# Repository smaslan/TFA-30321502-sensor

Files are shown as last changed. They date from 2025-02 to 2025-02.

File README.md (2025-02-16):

# TFA Dostmann 30.3215.02 compatible sensor

Recently, one of my meteo sensors TFA Dostmann 30.3215.02 died (rusted battery contacts). 
Not so long ago I decoded its data packets and made logging receiver for this particular type ([TFA-30321502-decoder](https://github.com/smaslan/TFA-30321502-decoder)). 
So, I decided to make a clone of this sensor based on the decoded format and it seems to work fine.

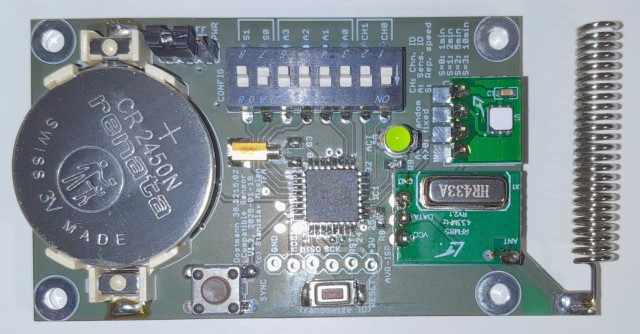
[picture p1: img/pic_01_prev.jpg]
Prototype


## Hardware

As usually, I used 8-bit AVR [ATmega48PB](https://www.microchip.com/en-us/product/atmega48pb).
Temperature and humidity sensor is [Hoperf TH06](https://www.hoperf.com/sensor/temperature_sensor/TH06.html).
Transmitter is cheap 433.92MHz module [Hoperf RFM85W-433](https://datasheet4u.com/datasheet-pdf/HOPERF/RFM85W-433D/pdf.php?id=748076) with AM modulation but it would work with any other module.
Both sensor and transmitter have switchable power to reduce idle consumption to near zero. Battery voltage sensing is also from the switched bus.
Intended power supply is from a single 3V cell Renata 2450n with approx. 500mAh capacity but it can of course run from 2xAAA cells or so.
Idle current is few uA and average charge consumed per single transmission is approx. 1uAh, so with 1 minute reporting period it should last about a year on the battery.
Configuration of the module is done by 8 DIP switches (see below).
Diagram and PCB in Eagle 6.5.0 are available at [TFA_sensor/](./TFA_sensor/) 

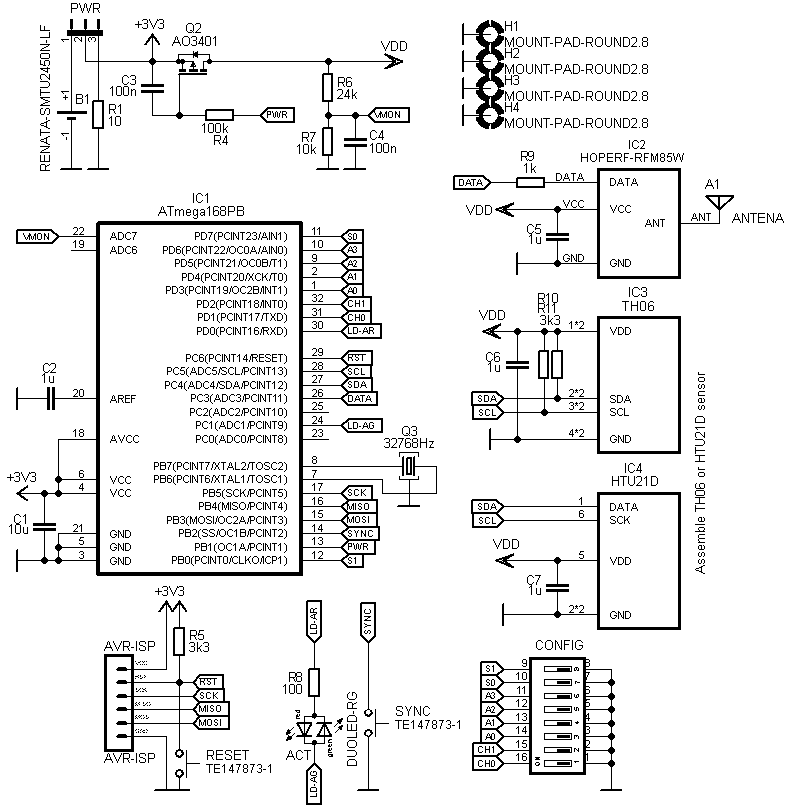
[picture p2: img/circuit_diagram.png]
Circuit diagram


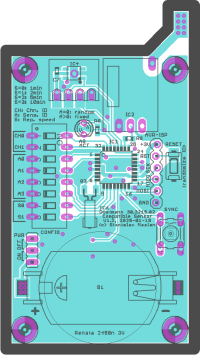
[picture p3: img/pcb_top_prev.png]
PCB top
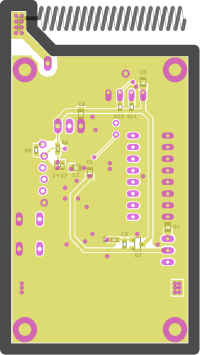
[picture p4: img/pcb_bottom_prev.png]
PCB bottom
 

## AVR Firmware

Firmware for AVR is written in [Microchip Studio](https://www.microchip.com/en-us/tools-resources/develop/microchip-studio) using AVRGCC compiler. 
AVR main clock is internal RC at 1MHz which is more than enough. Timer 2 is configured to use external 32768Hz crystal to periodically wakeup AVR from power save mode for the auto reporting.
Reporting period can be set by DIP switches and it is randomized +-5% to prevent permanent overlap with other sensors. Reporting can be also forced by SYNC button same as with original sensors.
Pressing RESET or cycling power will regenerate random device ID code same as with original sensor. 
When SYNC button or periodic wakeup occures, it will enable power bus, read sensor data and start transmission in format described in 
[TFA-30321502-decoder](https://github.com/smaslan/TFA-30321502-decoder). Then goes sleep again. The whole cycle takes less than 1 second (transmission is slow).
Dual color LED will blink green if battery voltage is ok and red if not.

DIP switches configuration:
```
CH[1..0]: Channel code, values 0, 1 and 2 (equal to original sensor switch positions 1, 2, 3), 
          this FW allows codes up to 3 but it won't be recognized by original meteo base station!
A[3..0]:  Sensor ID code: 0 will generate random ID after power up or RESET,
                          1 to 15 will force A value as sensor ID.
S[1..0]:  Reporting period (0: 1min, 1: 2min, 2: 5min, 3: 10min).                             
```

AVR fuse bits are set to default:
```
 Extended byte: BOOTRST = 1, BOOTSZ[1..0] = 00 
 High byte: BODLEVEL = 111, EESAVE = 1, WDTON = 1, SPIEN = 0, DWEN = 1, RSTDISBL = 1
 Low byte: CKSEL[3..0] = 0010, SUT[1..0] = 10, CKOUT = 1, CKDIV8 = 0
```
Firmware is available at [TFA_sensor/fw_tfa_sensor/](./TFA_sensor/fw_tfa_sensor).

## License
All parts of the project are distributed under [MIT license](./LICENSE.txt).

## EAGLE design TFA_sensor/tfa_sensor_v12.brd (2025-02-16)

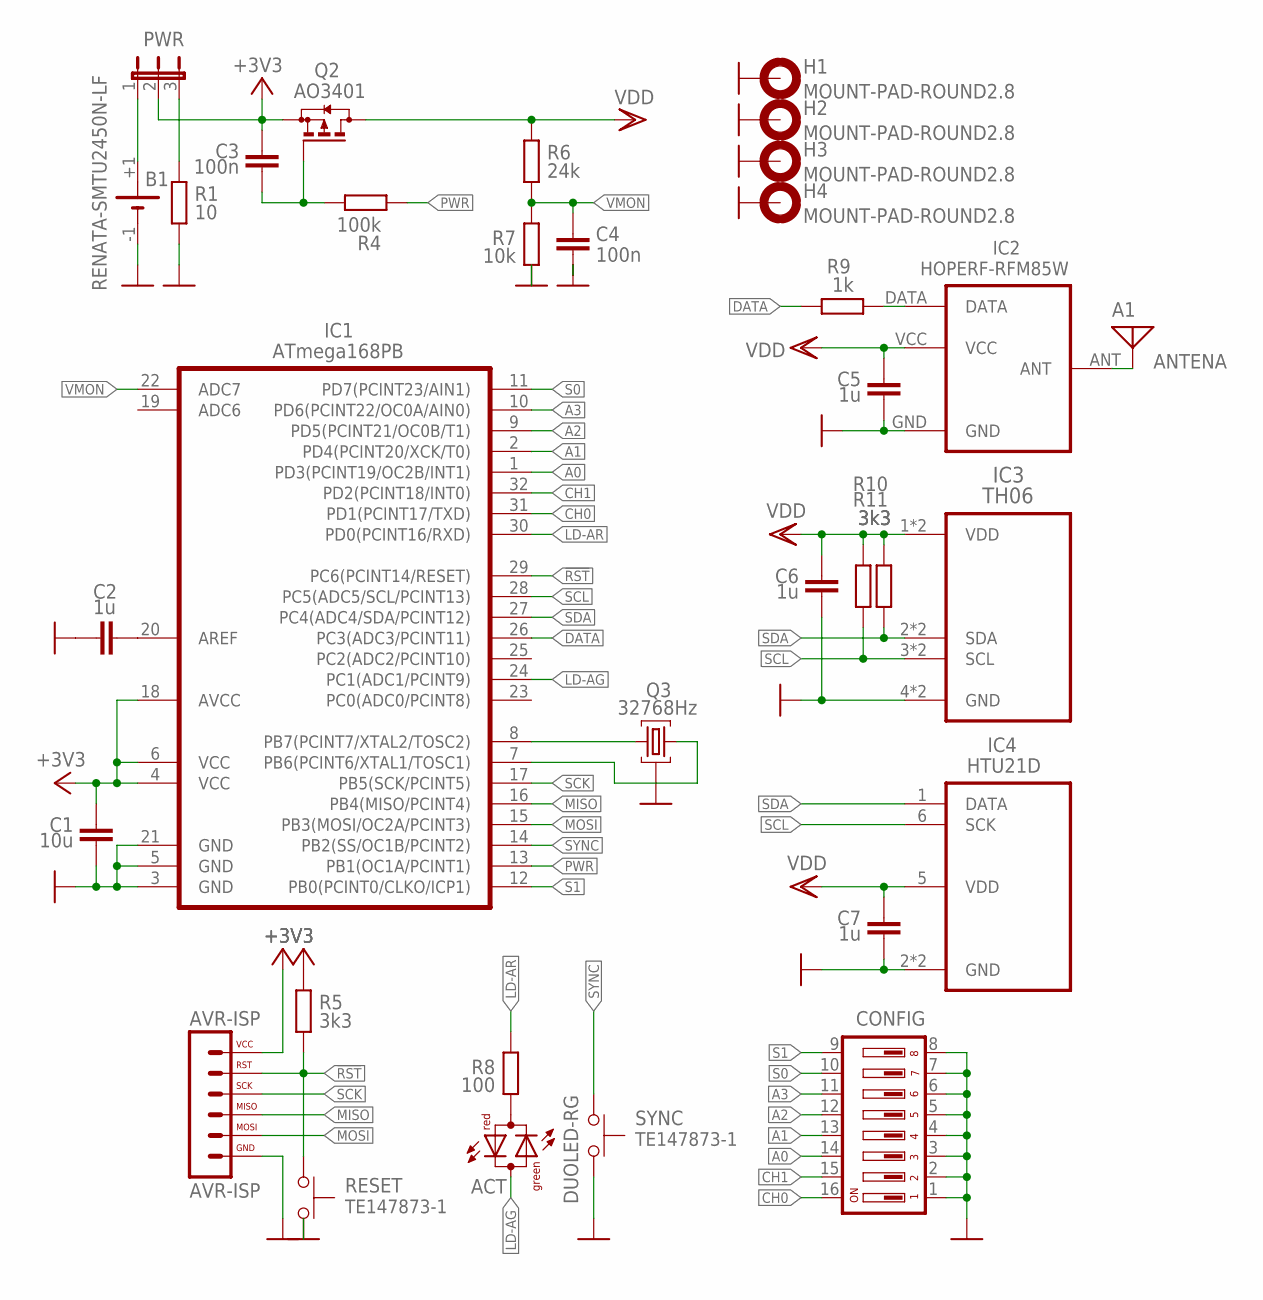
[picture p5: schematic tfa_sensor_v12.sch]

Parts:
A1: ANTENA; ANT-433MHZ-SPIRAL
ACT: DUOLED-RG; LED3MM
AVR-ISP: AVR-ISP; SIL6-RNDPRESS
B1: RENATA-SMTU2450N-LF
C1: 10u; C0805K
C2, C5, C6: 1u; C0805K
C3, C4: 100n; C0603K
C7: 1u; C0603K
CONFIG: DIP08YL
H1, H2, H3, H4: MOUNT-PAD-ROUND2.8; 2,8-PAD
IC1: ATmega168PB; TQFP32
IC2: HOPERF-RFM85W
IC3: TH06
IC4: HTU21D; DFN6-RH
PWR: JP2EB; JP2YB
Q2: AO3401; SOT23
Q3: 32768Hz; CMJ206T
R1: 10; R0805
R4: 100k; R0603
R5, R10, R11: 3k3; R0603
R6: 24k; R0603
R7: 10k; R0603
R8: 100; R0603
R9: 1k; R0603
RESET: TE147873-1; TE-147873-1
SYNC: TE147873-1; CUDL1

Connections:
!RST: AVR-ISP.5, IC1.29 (PC6(PCINT14/RESET)), R5.1, RESET.P$2
+3V3: AVR-ISP.6, C1.1, C3.1, IC1.4 (VCC), IC1.6 (VCC), IC1.18 (AVCC), PWR.2, Q2.2 (S), R5.2
A0: CONFIG.14, IC1.1 (PD3(PCINT19/OC2B/INT1))
A1: CONFIG.13, IC1.2 (PD4(PCINT20/XCK/T0))
A2: CONFIG.12, IC1.9 (PD5(PCINT21/OC0B/T1))
A3: CONFIG.11, IC1.10 (PD6(PCINT22/OC0A/AIN0))
ANT: A1.P$1, IC2.ANT
CH0: CONFIG.16, IC1.31 (PD1(PCINT17/TXD))
CH1: CONFIG.15, IC1.32 (PD2(PCINT18/INT0))
DATA: IC1.26 (PC3(ADC3/PCINT11)), R9.2
GND: AVR-ISP.1, B1.-1 (-), C1.2, C2.1, C4.2, C5.2, C6.2, C7.2, CONFIG.1, CONFIG.2, CONFIG.3, CONFIG.4, CONFIG.5, CONFIG.6, CONFIG.7, CONFIG.8, H1.B2,8, H2.B2,8, H3.B2,8, H4.B2,8, IC1.3 (GND), IC1.5 (GND), IC1.21 (GND), IC2.GND, IC3.4 (GND), IC3.14 (GND), IC4.2 (GND), IC4.EP (GND), Q3.S (3), R1.2, R7.1, RESET.P$1, SYNC.1, SYNC.2
LD-AG: ACT.K (C), IC1.24 (PC1(ADC1/PCINT9))
LD-AR: IC1.30 (PD0(PCINT16/RXD)), R8.2
MISO: AVR-ISP.3, IC1.16 (PB4(MISO/PCINT4))
MOSI: AVR-ISP.2, IC1.15 (PB3(MOSI/OC2A/PCINT3))
unnamed: B1.+1 (+), PWR.1
unnamed: PWR.3, R1.1
unnamed: ACT.A, R8.1
unnamed: IC1.8 (PB7(PCINT7/XTAL2/TOSC2)), Q3.X2 (2)
unnamed: IC1.7 (PB6(PCINT6/XTAL1/TOSC1)), Q3.X1 (1)
unnamed: C2.2, IC1.20 (AREF)
unnamed: IC2.DATA, R9.1
unnamed: C3.2, Q2.1 (G), R4.2
PWR: IC1.13 (PB1(OC1A/PCINT1)), R4.1
S0: CONFIG.10, IC1.11 (PD7(PCINT23/AIN1))
S1: CONFIG.9, IC1.12 (PB0(PCINT0/CLKO/ICP1))
SCK: AVR-ISP.4, IC1.17 (PB5(SCK/PCINT5))
SCL: IC1.28 (PC5(ADC5/SCL/PCINT13)), IC3.3 (SCL), IC3.13 (SCL), IC4.6 (SCK), R10.2
SDA: IC1.27 (PC4(ADC4/SDA/PCINT12)), IC3.2 (SDA), IC3.12 (SDA), IC4.1 (DATA), R11.2
SYNC: IC1.14 (PB2(SS/OC1B/PCINT2)), SYNC.3, SYNC.4
VDD: C5.1, C6.1, C7.1, IC2.VCC, IC3.1 (VDD), IC3.11 (VDD), IC4.5 (VDD), Q2.3 (D), R6.2, R10.1, R11.1
VMON: C4.1, IC1.22 (ADC7), R6.1, R7.2

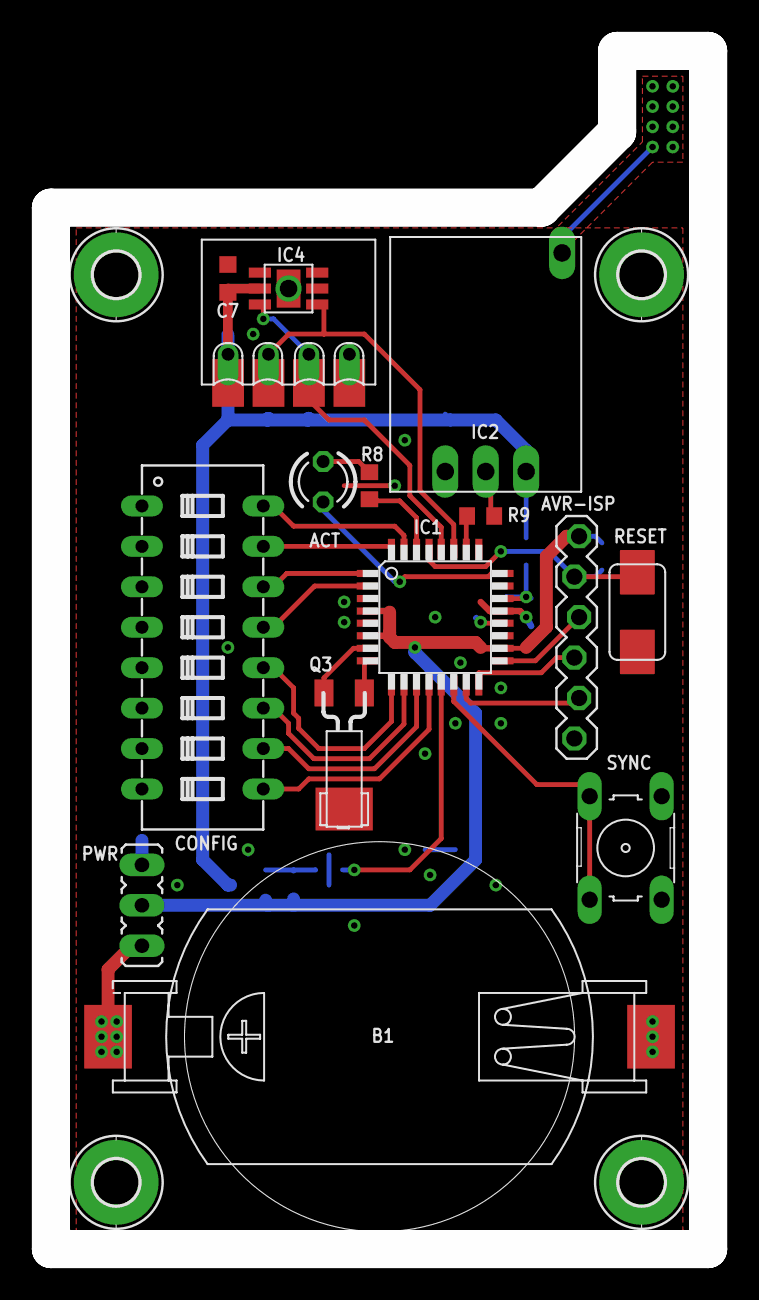
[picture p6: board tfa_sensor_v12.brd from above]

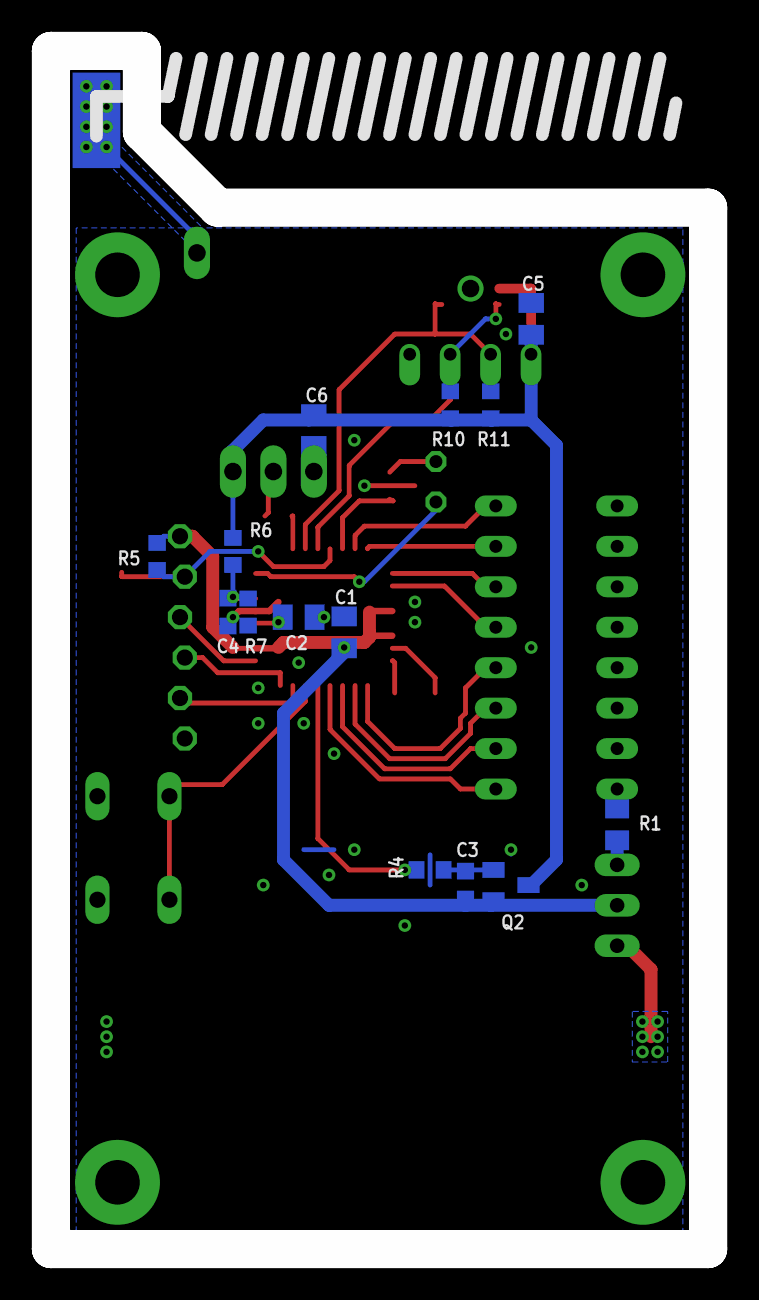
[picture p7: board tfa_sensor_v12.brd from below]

Board: 2 copper layers, 41.3 x 75.2 mm, 34 parts (15 on the bottom side), 32 nets.

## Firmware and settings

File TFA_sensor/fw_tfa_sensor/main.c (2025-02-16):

/*
 * TFA Dostmann 30.3215.02 compatible sensor transmitter.
 * This code uses TH06 ambient sensor to periodically read temperature and RH
 * and sends packet compatible with TFA Dostmann 30.3215.02 sensors via any 433.92MHz radio module.
 *
 * Sensor channel code 1 to 4 is defined by DIP switches.
 * Sensor identifier is set either manually by DIPs in range 1 to 15 or random after each reset as for original sensor when DIPs set to 0.
 * Reporting period can be set to 1, 2, 5 or 10 minutes by another DIPs. Actual period is randomized +/-5%.
 *
 * Designed for ATmega48PB, which is about minimum to fit.
 * Wakeup timer uses 32768Hz crystal on Timer 2.
 * Main clock is internal 1MHz RC clock (default fuses).
 * It is designed for a 3V lithium battery Renata 2450n with ~500mAh capacity.
 * It should last for about a year with 1 minute reporting period (consumes ~1uAh per transmission).
 * Idle power is few uA. Actual lifetime depends on transmitter power.
 *
 * More details on HW on project GitHub url:
 * https://github.com/smaslan/TFA-30321502-sensor
 *
 * (c) 2025, Stanislav Maslan, s.maslan@seznam.cz
 * V1.2, 2025-02-15
 *
 * The code and all its part are distributed under MIT license
 * https://opensource.org/licenses/MIT.
 */ 

#include <avr/io.h>
#include <avr/sleep.h>
#include <avr/pgmspace.h>
#include <avr/interrupt.h>
#include <avr/wdt.h>
#include <avr/sfr_defs.h>
#include <util/twi.h>
#include <util/atomic.h>
#include <util/delay_basic.h>
#include <util/delay.h>
#include <stdlib.h>

#include "main.h"

// --- jump to address ---
#define boot_start(boot_addr) {goto *(const void*)boot_addr;}



//----------------------------------------------------------------------------------
// analog ADC stuff
//----------------------------------------------------------------------------------

// ADC data and stuff
typedef struct{
	volatile uint16_t a_vmon;
	volatile uint8_t rand;
}TADC;
TADC adc_data;

#define ADC_VREF 1.1f
#define ADC_VMON_DIV (10000.0/(10000.0 + 24000.0))
#define ADC_GAIN (ADC_VREF/(ADC_AVG*1024.0f))
#define ADC_VMON_CAL (ADC_GAIN/ADC_VMON_DIV)

// ADC conversion done ISR
ISR(ADC_vect)
{
	// average buffer
	static uint8_t avg_cnt = ADC_AVG;

	// get new value
	uint16_t adc = ADC;
		
	static uint16_t vmon = 0;
	vmon += adc;
	avg_cnt--;
	if(!avg_cnt)
	{
		avg_cnt = ADC_AVG;
		adc_data.a_vmon = vmon; vmon = 0;

		// generate random-like number
		uint8_t rng = (adc&0xFF)^(adc>>8);
		rng = (rng>>4)^(rng&0x0F);
		rng = (rng>>2)^(rng&0x03);
		rng = (rng>>1)^(rng&0x01);
		adc_data.rand = (adc_data.rand<<1) | rng;
	}
	
	// start next conversion
	sbi(ADCSRA,ADIF);
	sbi(ADCSRA,ADSC);
}

// get VMON voltage [V]
float adc_get_vmon()
{
	uint16_t a_vmon = 0;
	ATOMIC_BLOCK(ATOMIC_RESTORESTATE)
	{
		a_vmon = adc_data.a_vmon;
	}
	return(ADC_VMON_CAL*a_vmon);
}


// init ADC
void adc_init()
{
	// initial ADC setup (AVcc ref)
	ADMUX = (3<<REFS0)|(0<<ADLAR)|(VMON_ADC_MUX<<MUX0);
	ADCSRA = (1<<ADEN)|(0<<ADATE)|(1<<ADIE)|(2<<ADPS0);
	ADCSRB = (0<<ADTS0);
	
	// start ADC conversion loop
	sbi(ADCSRA,ADSC);
	
	// initial measured value
	adc_data.a_vmon = 0;
}

// idle ADC before sleep
void adc_idle()
{
	ADCSRA = 0;
}


//----------------------------------------------------------------------------------
// DIP switches stuff
//----------------------------------------------------------------------------------
// init DIP switches
void dip_init()
{
	// channel
	CH_ddr &= ~(CH_msk<<CH0);
	CH_port |= (CH_msk<<CH0);

	// address id
	A_ddr &= ~(A_msk<<A0);
	A_port |= (A_port<<A0);

	// speed code
	cbi(S0_ddr, S0);
	sbi(S0_port, S0);
	cbi(S1_ddr, S1);
	sbi(S1_port, S1);
}

// set DIP to power down mode
void dip_idle()
{
	CH_port &= ~(CH_msk<<CH0);
	A_port &= ~(A_msk<<A0);
	cbi(S0_port, S0);
	cbi(S1_port, S1);
}

// get address id
uint8_t dip_get_addr()
{
	return(15 - ((A_pin >> A0) & A_msk));
}

// get channel id
uint8_t dip_get_chn()
{
	return(3 - ((CH_pin >> CH0) & CH_msk));
}

// get speed code
uint8_t dip_get_speed()
{
	uint8_t speed = 0;
	bcopy(speed, 0, S0_pin, S0);
	bcopy(speed, 1, S1_pin, S1);
	return(3 - speed);
}





//----------------------------------------------------------------------------------
// I2C STUFF
//----------------------------------------------------------------------------------

#define i2c_start() TWCR = (1<<TWINT) | (1<<TWEN) | (1<<TWSTA)
#define i2c_stop() TWCR = (1<<TWINT) | (1<<TWEN) | (1<<TWSTO)
#define i2c_data_out(data)	TWDR = (data); TWCR = (1<<TWINT) | (1<<TWEN)
#define i2c_read(ack) TWCR = (1<<TWINT) | (1<<TWEN) | ((ack)<<TWEA)

// set timeout value [ms]
volatile uint16_t i2c_timeout;
void i2c_timeout_set(uint16_t timeout)
{
	ATOMIC_BLOCK(ATOMIC_FORCEON)
	{
		i2c_timeout = timeout;
	}
}

// timeout done?
uint8_t i2c_timeout_done()
{
	uint16_t timeout;
	ATOMIC_BLOCK(ATOMIC_FORCEON)
	{
		timeout = i2c_timeout;
	}
	return(timeout == 0);
}

// timeout timer ISR
ISR(TIMER0_COMPA_vect, ISR_NOBLOCK)
{
	uint16_t time = i2c_timeout;
	if(time)
		time--;
	i2c_timeout = time;
}

// initialize I2C
void i2c_init()
{
	// I2C as master
	TWCR = (1<<TWEN)|(1<<TWEA);
	TWBR = (uint8_t)((F_CPU - 16.0*I2C_FREQ)/(2.0*I2C_FREQ));
	TWSR = (0<<TWPS0);

	// timeout timer
	i2c_timeout = 0;
	TCCR0A = (2<<WGM00);
	TCCR0B = (0<<WGM02)|(2<<CS00);
	OCR0A = (uint8_t)((1.0e-3*F_CPU/8) - 1);
	TIMSK0 = (1<<OCIE0A);
	
	// enable pull-ups
	sbi(I2C_port,I2C_SDA);
	sbi(I2C_port,I2C_SCL);
}

// idle I2C stuff
void i2c_idle()
{
	// stop I2C
	TWCR = 0;
	
	// stop timeout timer
	TCCR0B = (0<<WGM02)|(0<<CS00);
	
	// idle lines
	cbi(I2C_port,I2C_SDA);
	cbi(I2C_port,I2C_SCL);
}



// wait for I2C state change with timeout (ISR must be enabled!)
uint8_t i2c_wait(uint16_t timeout_ms)
{
	if(timeout_ms)
	{
		// timeout mode
		i2c_timeout_set(timeout_ms);
		while(!bit_is_set(TWCR,TWINT) && !i2c_timeout_done());
		return(i2c_timeout_done());
	}
	else
		while(!bit_is_set(TWCR,TWINT)); // no timeout mode

	return(0);
}

// I2C write and read back routine with timeouts (ISR must be enabled)
// reads to the same data register, if no read needed, set rd_count to zero
uint8_t i2c_write_read_data(uint8_t address,uint8_t *data,uint8_t wr_count,uint8_t rd_count,uint16_t timeout_ms)
{
	// start
	i2c_start();
	if(i2c_wait(timeout_ms))
	{
		// timeout
		i2c_stop();
		return(1);
	}
	if((TW_STATUS) != TW_START)
	{
		i2c_stop();
		return(1);
	}

	// send address + write
	i2c_data_out(address<<1);
	if(i2c_wait(timeout_ms))
	{
		// timeout
		i2c_stop();
		return(2);
	}
	if((TW_STATUS) != TW_MT_SLA_ACK)
	{
		i2c_stop();
		return(2);
	}

	// transmit data bytes
	for(uint8_t k = 0;k < wr_count;k++)
	{
		// send byte
		i2c_data_out(data[k]);
		if(i2c_wait(timeout_ms))
		{
			// timeout
			i2c_stop();
			return(3);
		}
		if((TW_STATUS) != TW_MT_DATA_ACK)
		{
			i2c_stop();
			return(3);
		}
	}

	// optional read data
	if(rd_count)
	{
		// restart
		i2c_start();
		if(i2c_wait(timeout_ms))
		{
			// timeout
			i2c_stop();
			return(4);
		}
		if((TW_STATUS) != TW_REP_START)
		{
			i2c_stop();
			return(4);
		}

		// send address + read
		i2c_data_out((address<<1) | 0x01);
		if(i2c_wait(timeout_ms))
		{
			// timeout
			i2c_stop();
			return(5);
		}
		if((TW_STATUS) != TW_MR_SLA_ACK)
		{
			i2c_stop();
			return(5);
		}

		// read data bytes
		for(uint8_t k = 0;k < rd_count;k++)
		{
			// read byte
			i2c_read(k < rd_count-1);
			if(i2c_wait(timeout_ms))
			{
				// timeout
				i2c_stop();
				return(6);
			}
			if((TW_STATUS) != TW_MR_DATA_ACK && (TW_STATUS) != TW_MR_DATA_NACK)
			{
				i2c_stop();
				return(6);
			}
			data[k] = TWDR;
		}

	}

	// stop
	i2c_stop();

	
	return(0);
}

// timeout in case I2C fails [ms]
#define I2C_TIMEOUT 100
#define TH06_I2C_ADDRESS 0x40u
#define TH06_CMD_TEMP_READ_HOLD 0xE3u
#define TH06_CMD_RH_READ_HOLD 0xE5u
#define TH06_CMD_TEMP_READ_LAST 0xE0u

// random number from TH06 sensor
uint8_t th06_rng;

// get TH06 relative humidity (call before temperature read - it measures both)
uint8_t TH06_get_rh(uint8_t *rh)
{
	// default return
	*rh = 0.0;

	// read temp blocking
	uint8_t data[2] = {TH06_CMD_RH_READ_HOLD,0};
	uint8_t err = i2c_write_read_data(TH06_I2C_ADDRESS, data, 1, 2, I2C_TIMEOUT);
	if(err)
		return(err);
	
	// convert to float
	uint16_t read = data[1] + (data[0]<<8);
	*rh = (uint8_t)(125.0*read/65536.0 - 6.0);

	// update random generator
	th06_rng = data[0] ^ data[1];
	
	return(err);
}

// get TH06 temperature (last measured by previous RH measurement)
uint8_t TH06_get_temp(int16_t *temp)
{
	// default return
	*temp = 0;

	// read temp blocking
	uint8_t data[2] = {TH06_CMD_TEMP_READ_LAST,0};
	uint8_t err = i2c_write_read_data(TH06_I2C_ADDRESS, data, 1, 2, I2C_TIMEOUT);
	if(err)
	return(err);
	
	// convert to float
	uint16_t read = data[1] + (data[0]<<8);
	*temp = (int16_t)((175.72*read/65536.0 - 46.85)*10.0);

	// update random generator
	th06_rng = data[0] ^ data[1];
	
	return(err);
}





//----------------------------------------------------------------------------------
// Transmitter stuff
//----------------------------------------------------------------------------------

typedef struct{
	uint8_t data[5];
	uint8_t bit_pos;
	uint8_t state;
	uint8_t pulse;
	uint8_t packet;
}TTX;
TTX tx;

#define TX_STATE_IDLE 0
#define TX_STATE_START 1
#define TX_STATE_DATA 2
#define TX_STATE_STOP 3
#define TX_STATE_FINISHED 4

#define TX_BIT_W_MS 0.5e-3
#define TX_BIT_W ((uint16_t)(TX_BIT_W_MS*F_CPU))
#define TX_BIT_START_W ((uint16_t)((9.0e-3 - TX_BIT_W_MS)*F_CPU))
#define TX_BIT_STOP_W ((uint16_t)((1.5e-3 - TX_BIT_W_MS)*F_CPU))
#define TX_BIT_HIGH_W ((uint16_t)((4.2e-3 - TX_BIT_W_MS)*F_CPU))
#define TX_BIT_LOW_W ((uint16_t)((2.3e-3 - TX_BIT_W_MS)*F_CPU))

// bit timer
ISR(TIMER1_COMPA_vect)
{
	// send last iteration pulse out
	if(tx.pulse)
		sbi(DATA_port, DATA)
	else
		cbi(DATA_port, DATA)		

	if(tx.pulse)
	{
		// start pulse
		tx.pulse = 0;
		OCR1A = TX_BIT_W;
	}
	else
	{
		// pulse ended

		// initiate new pulse?
		if(tx.state != TX_STATE_IDLE)
		{
			tx.pulse = 1;
		}

		
		if(tx.state == TX_STATE_START)
		{
			// start bit
			OCR1A = TX_BIT_START_W;
			tx.state = TX_STATE_DATA;
		}
		else if(tx.state == TX_STATE_DATA)
		{
			// data bits
			static const uint8_t mask[] PROGMEM = {0x01, 0x02, 0x04, 0x08, 0x10, 0x20, 0x40, 0x80};
			uint8_t bit_pos = tx.bit_pos - 1;
			uint8_t data = tx.data[bit_pos >> 3] & pgm_read_byte(&mask[bit_pos & 0x07]);
			if(data)
				OCR1A = TX_BIT_HIGH_W;
			else
				OCR1A = TX_BIT_LOW_W;
			
			if(!bit_pos)
			{				
				// last bit out
				bit_pos = 36;
				tx.packet--;				
				tx.state = TX_STATE_STOP;
			}
			tx.bit_pos = bit_pos;
			
		}
		else if(tx.state == TX_STATE_STOP)
		{
			// stop bit
			OCR1A = TX_BIT_STOP_W;
			if(tx.packet)
			{
				// start next packet repetition
				tx.state = TX_STATE_START;
			}
			else
			{
				// all packets out - finish after stop pulse
				tx.state = TX_STATE_IDLE;
			}
		}
		else
		{
			// all finished
			tx.state = TX_STATE_FINISHED;
			
			// stop bit timer
			TCCR1B = (1<<WGM12)|(0<<CS10);
			TIMSK1 = 0;
		}
	}	
}

// init transmitter
void tx_init()
{
	// init TX pin
	sbi(DATA_ddr, DATA);
	cbi(DATA_port, DATA);
	tx.state = TX_STATE_IDLE;
}

// set transmitter to idle state
void tx_idle()
{
	// data port to idle
	cbi(DATA_port, DATA);

	// stop bit timer
	TCCR1B = (1<<WGM12)|(0<<CS10);
	TIMSK1 = 0;
}

// start data packet transmission
void tx_start()
{
	// start bit timer
	OCR1A = 65535;
	TCNT1 = 0;
	TCCR1A = (0<<WGM10);
	TCCR1B = (1<<WGM12)|(1<<CS10);
	TIFR1 = 0xFF;
	TIMSK1 = (1<<OCIE1A);
		
	// init transmitter state machine
	tx.state = TX_STATE_START;
	tx.bit_pos = 36;
	tx.packet = 7;
	tx.pulse = 1;
	
	// start transmission
	TCCR1C = (1<<FOC1A);
}

// check if transmission done
uint8_t tx_is_done()
{
	return(tx.state == TX_STATE_FINISHED);
}


//----------------------------------------------------------------------------------
// system timer
//----------------------------------------------------------------------------------

// update timer period
volatile uint16_t tick_periods;
volatile uint16_t tick_div;
void timer_set(uint16_t period)
{
	// timer tick rate [s]
	const float tick = 1024.0/TICK_REFCLK;
	// timer period randomization const
	const uint8_t tick_rand = (uint8_t)(2.0*TICK_PER_RAND/tick);
	// timer period const
	const uint8_t tick_int = (uint8_t)((TICK_PER - TICK_PER_RAND)/tick);
	// set new rate	
	OCR2A = tick_int + (rand() % tick_rand);

	// timer periods multiplier
	ATOMIC_BLOCK(ATOMIC_RESTORESTATE)
	{
		tick_periods = max((uint8_t)((float)period/TICK_PER),1);	
		tick_div = tick_periods;
	}
}

// init system timer
volatile uint8_t tick_flag;
void timer_init()
{
	// default period
	timer_set(5);

	// init with external crystal
	TCCR2A = (2<<WGM20);
	TCCR2B = (0<<WGM22) | (7<<CS20);
	ASSR = (0<<EXCLK) | (1<<AS2);
	TIMSK2 = 1<<OCIE2A;
	tick_flag = 0;
}

// wakeup timer
ISR(TIMER2_COMPA_vect)
{
	tick_div--;
	if(!tick_div)
	{
		tick_div = tick_periods;
		tick_flag = 1;
	}
}


//----------------------------------------------------------------------------------
// Other
//----------------------------------------------------------------------------------
// power off
void pwr_idle()
{
	sbi(PWR_ddr, PWR);
	sbi(PWR_port, PWR);
}

// power on
void pwr_enable()
{
	sbi(PWR_ddr, PWR);
	cbi(PWR_port, PWR);
}

// set LED state
#define LED_OFF 0
#define LED_GREEN 1
#define LED_RED 2
void led_state(uint8_t state)
{
	sbi(LEDAR_ddr, LEDAR);
	sbi(LEDAG_ddr, LEDAG);
	if(state == LED_GREEN)
	{
		sbi(LEDAG_port, LEDAG);
		cbi(LEDAR_port, LEDAR);	
	}
	else if(state == LED_RED)
	{
		sbi(LEDAR_port, LEDAR);
		cbi(LEDAG_port, LEDAG);
	}
	else
	{
		cbi(LEDAR_port, LEDAR);
		cbi(LEDAG_port, LEDAG);
	}
}

// init SYNC button
volatile uint8_t sync_flag;
void sync_init()
{
	// sync input with pullup
	cbi(SYNC_ddr, SYNC);
	sbi(SYNC_port, SYNC);
	
	// enable ISR
	SYNC_PCMSK = (1<<SYNC);
	PCICR = (1<<SYNC_PCIE);

	// no sync request yet
	sync_flag = 0;
}

// SYNC button ISR
ISR(SYNC_ISR)
{
	if(!bit_is_set(SYNC_pin, SYNC))
		sync_flag = 1;
}




//----------------------------------------------------------------------------------
// MAIN
//----------------------------------------------------------------------------------
int main(void)
{
	// disable WDT if enabled (sometimes it fucks up ...)
	uint8_t rst_flag = MCUSR;
	MCUSR = 0;
	wdt_disable();

	// disable all ports
	DDRB = 0x00;
	DDRC = 0x00;
	DDRD = 0x00;
	
	if(bit_is_set(rst_flag,BORF))
	{
		// brown-out reset
		_delay_ms(200);
	}

	PRR = (1<<PRUSART0) | (1<<PRSPI);
		
	// init ADC
	adc_init();
	adc_idle();

	// init DIP switches
	dip_init();
	dip_idle();

	// init transmitter
	tx_init();
	tx_idle();

	// init I2C bus
	i2c_init();
	i2c_idle();

	// idle power stage
	pwr_idle();

	// init SYNC button
	sync_init();

	// init periodic wakeup timer
	timer_init();

	// state LED
	led_state(LED_OFF);

	// default sensor ID
	uint8_t addr_rand = 0;

	// initial channel id unknown
	uint8_t chn_id_last = 255;
	
	// enable ISR
	sei();
			
	
	while(1)
	{		
		// init stuff
		pwr_enable();
		i2c_init();
		adc_init();
		tx_init();

		// wait for power up
		_delay_ms(100);
						
		// read temperature and RH from TH06
		int16_t temp = 0;
		uint8_t rh = 0;
		TH06_get_rh(&rh);
		TH06_get_temp(&temp);
							
		// get system voltage (should be updated at this point)
		float vmon = adc_get_vmon();
		uint8_t low_batt = vmon < VMON_MIN;

		// idle ADC, init DIPs
		adc_idle();
		dip_init();

		// get sensor channel
		uint8_t chn_id = dip_get_chn();
		if(chn_id != chn_id_last)
		{
			// randomizing sensor id whenever channel changed (and after reset)
			
			// regenerate seed?			
			uint8_t seed = TCNT2 ^ adc_data.rand ^ th06_rng;
			if(chn_id_last == 255)
				srand(seed);
						
			// generate new sensor id			
			addr_rand = (seed&0x0F) ^ (seed>>4);
		}
		chn_id_last = chn_id;
		
		// select sensor id (fixed or random)
		uint8_t addr = dip_get_addr();
		if(!addr)
			addr = addr_rand;

		// update auto report period
		uint8_t speed_code = dip_get_speed();
		static const uint16_t speed_list[] PROGMEM = {60, 120, 300, 600};
		uint16_t speed = pgm_read_word(&speed_list[speed_code]);
		timer_set(speed);

		// make data packet
		tx.data[4] = 0x09;
		tx.data[3] = 0x00 | addr;
		tx.data[2] = (low_batt<<7) | (sync_flag<<6) | (chn_id<<4) | ((temp >> 8) & 0x0F);
		tx.data[1] = temp & 0xFF;
		tx.data[0] = rh;

		dip_idle();
			
		// start transmission
		tx_start();

		// blink state led based on battery state
		led_state((low_batt)?LED_RED:LED_GREEN);
		_delay_ms(10);
		led_state(LED_OFF);

		// wait till transmission is finished		
		while(!tx_is_done())
			_delay_ms(1);		

		// idle transmitter
		tx_idle();

		// idle I2C bus
		i2c_idle();

		// idle power stage
		pwr_idle();

		// clear auto report tick flag
		tick_flag = 0;
		sync_flag = 0;

		do{
			// go to sleep
			cli();
			MCUCR = (1<<BODSE)|(1<<BODS);
			MCUCR = (1<<BODS);
			set_sleep_mode(SLEEP_MODE_PWR_SAVE);
			sleep_enable();
			sleep_bod_disable();
			sei();
			sleep_cpu();
			sleep_disable();
			
			// wait till SYNC or auto report tick (ignoring wakeup timer ticks until report period reached)
		}while(!sync_flag && !tick_flag);		
		
	}

}

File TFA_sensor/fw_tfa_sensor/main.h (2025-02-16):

#ifndef MAIN_H
#define MAIN_H

// general macros
#define sbi(port,pin) {(port)|=(1<<pin);}
#define cbi(port,pin) {(port)&=~(1<<pin);}
#define min(a,b) ((a<b)?(a):(b))
#define max(a,b) ((a>b)?(a):(b))
#define bcopy(dreg,dpin,srreg,srpin) if(bit_is_set((srreg),(srpin))){sbi(dreg,dpin);}else{cbi(dreg,dpin);}
#define bcopy_v(dreg,dpin,srreg,srpin) if((srreg)&(1<<srpin)){sbi(dreg,dpin);}else{cbi(dreg,dpin);}
#define low(x) ((x) & 0xFFu)
#define high(x) (((x)>>8) & 0xFFu)

// I2C
#define I2C_port PORTC
#define I2C_ddr DDRC
#define I2C_pin PINC
#define I2C_SDA PC4
#define I2C_SCL PC5

// radio TX data
#define DATA_port PORTC
#define DATA_ddr DDRC
#define DATA PC3

// power enable (active low)
#define PWR_port PORTB
#define PWR_ddr DDRB
#define PWR PB1

// power monitor ADC
#define VMON_ADC_MUX 0x07 /* VMON adc channel mux input */

// status LED
#define LEDAR_port PORTD
#define LEDAR_ddr DDRD
#define LEDAR PD0
#define LEDAG_port PORTC
#define LEDAG_ddr DDRC
#define LEDAG PC1

// sync button
#define SYNC_port PORTB
#define SYNC_ddr DDRB
#define SYNC_pin PINB
#define SYNC PB2
#define SYNC_PCIE PCIE0
#define SYNC_PCMSK PCMSK0 
#define SYNC_ISR PCINT0_vect

// DIP: channel
#define CH_port PORTD
#define CH_ddr DDRD
#define CH_pin PIND
#define CH0 PD1
#define CH1 PD2
#define CH_msk 0x03

// DIP: address id
#define A_port PORTD
#define A_ddr DDRD
#define A_pin PIND
#define A0 PD3
#define A1 PD4
#define A2 PD5
#define A3 PD6
#define A_msk 0x0F

// DIP: speed
#define S0_port PORTD
#define S0_ddr DDRD
#define S0_pin PIND
#define S0 PD7
#define S1_port PORTB
#define S1_ddr DDRB
#define S1_pin PINB
#define S1 PB0


// ADC averaging
#define ADC_AVG 16 /* 10bit*64 to scale to full 16bit */


#define I2C_FREQ 100000 /* I2C bus clock rate [Hz] */

#define VMON_MIN 2.4 /* minimum battery voltage [V] */

#define TICK_REFCLK 32768.0 /* reference clock rate [Hz] */
#define TICK_PER 5.0 /* mean wakeup tick rate [s] */
#define TICK_PER_RAND 0.25 /* wakeup tick rate randomization [s] */





#endif
